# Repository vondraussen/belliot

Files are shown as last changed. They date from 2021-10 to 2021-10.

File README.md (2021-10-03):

# Belliot
Door Bell IoT Hardware.
Made with Kicad.

Used to make my door intercom system a bit more smarter. I have a Siedle HT511-01 which I wanted to control from Home Assistant.

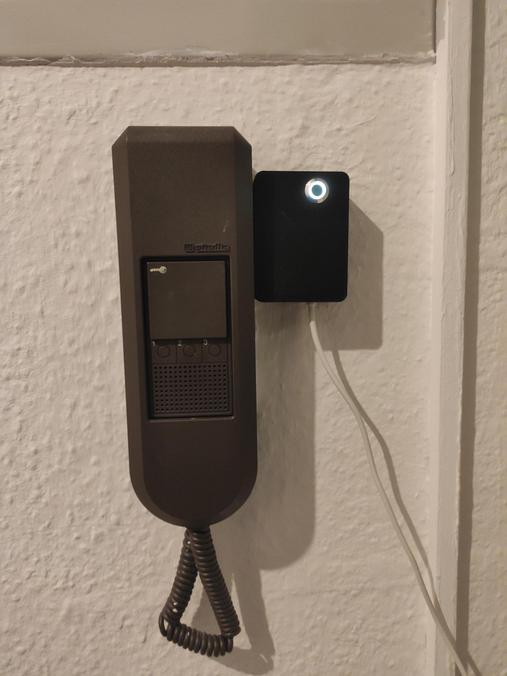
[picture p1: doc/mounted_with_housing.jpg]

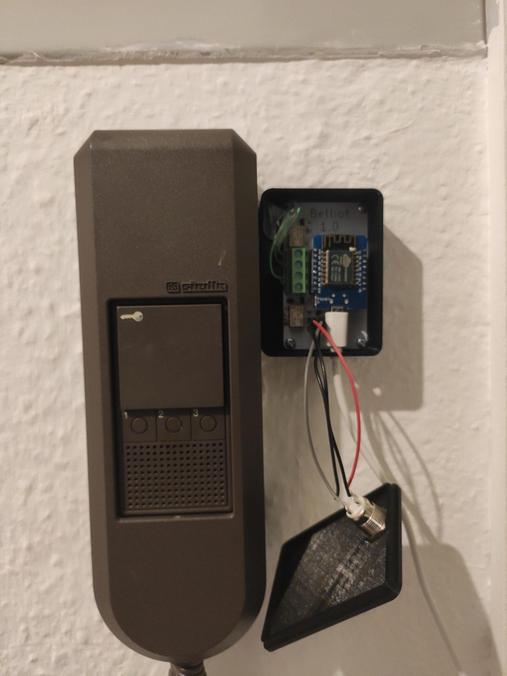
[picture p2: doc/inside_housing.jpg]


## Features
+ Mute bell via relay
+ Actuate door opener via relay
+ One button to mute/unmute bell at the hardware
+ One LED to indicate mute state

## Hardware
+ ESP8266 WeMos D1 Mini
+ AC Optocoupler VOS628A-3T
+ 2x Relais G6K-2F-Y

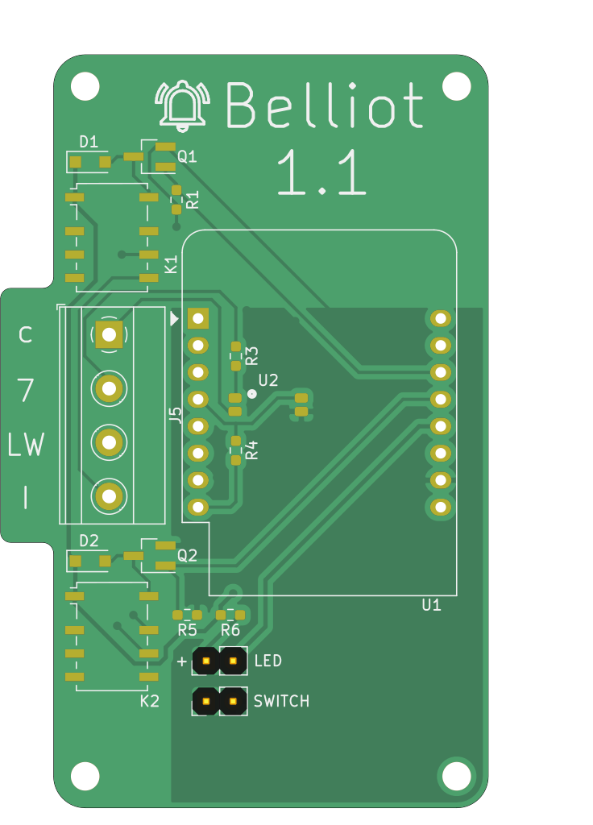
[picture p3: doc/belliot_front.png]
front

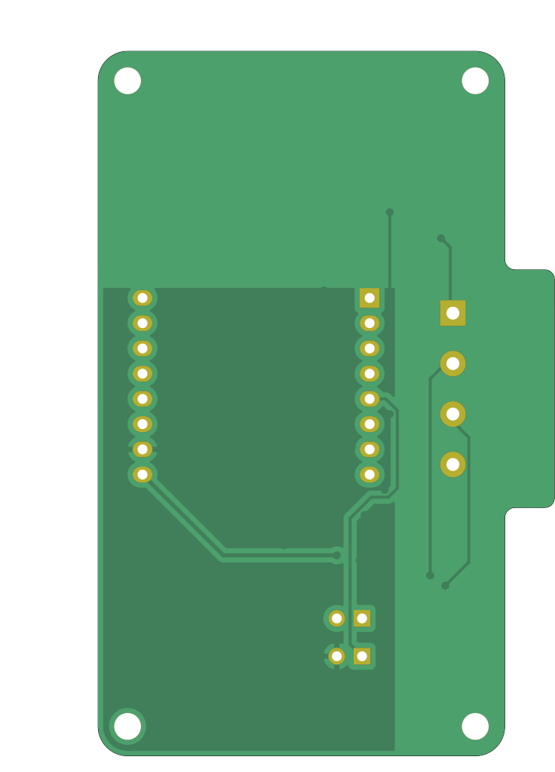
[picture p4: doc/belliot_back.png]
back


## Housing
Todo

## Software
The software repository is [belliot_sw](https://github.com/vondraussen/belliot_sw).

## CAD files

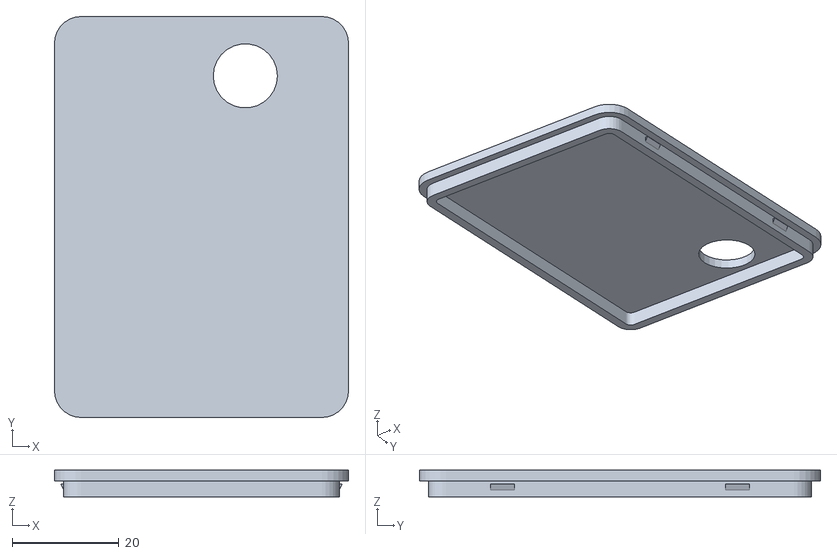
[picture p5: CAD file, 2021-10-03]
housing/belliot-upper_housing.stl
55.0 x 75.0 x 5.00

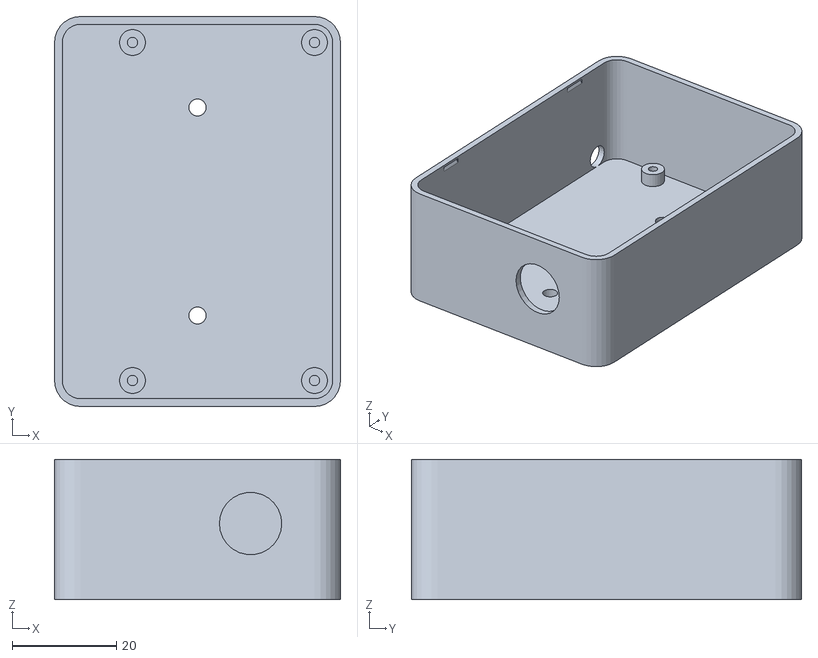
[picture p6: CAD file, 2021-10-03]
housing/belliot-lower_housing.stl
55.0 x 75.0 x 27.0

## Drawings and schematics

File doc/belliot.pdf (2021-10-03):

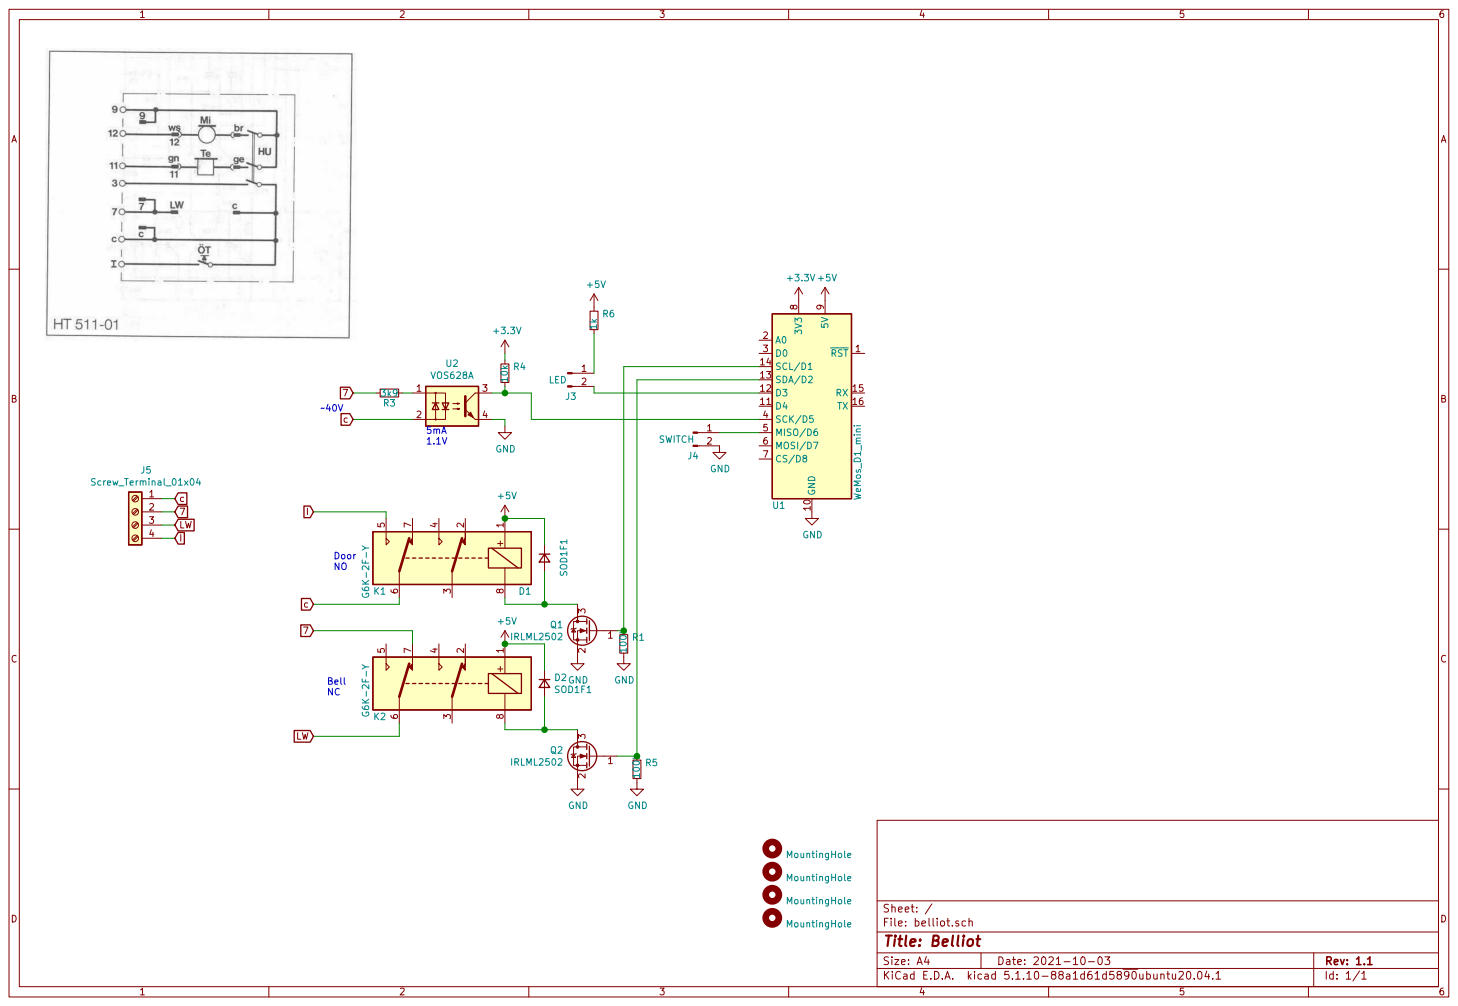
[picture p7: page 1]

Id: 1/1 Title: Belliot File: belliot.sch Sheet: / 1

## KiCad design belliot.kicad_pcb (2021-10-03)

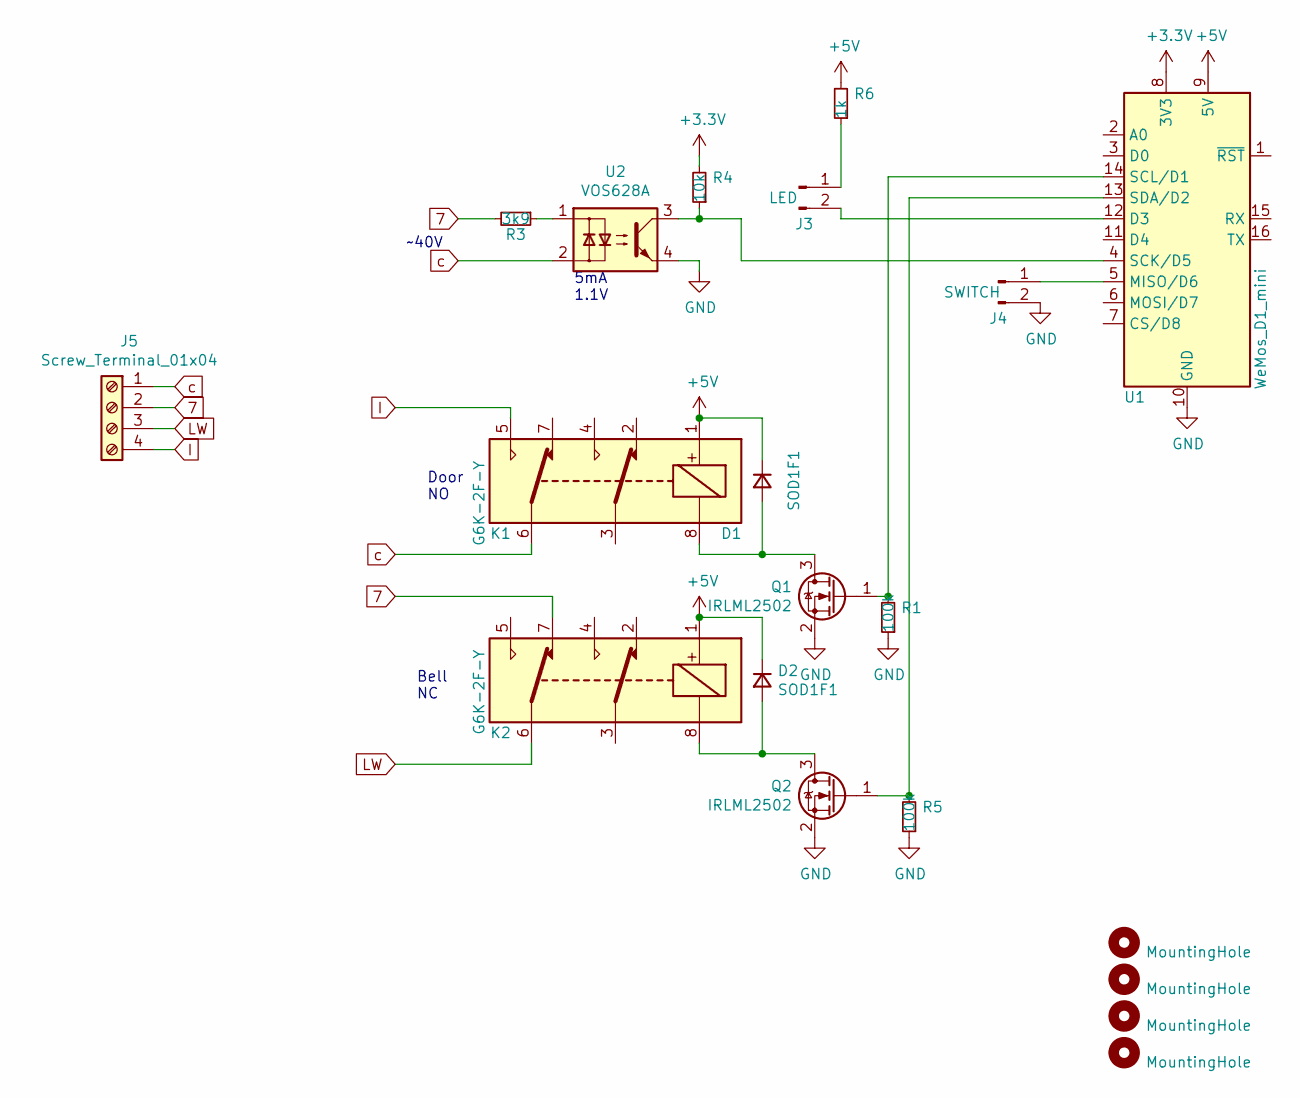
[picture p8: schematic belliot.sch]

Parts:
D1, D2: SOD1F1; D_SOD-123F; LCSC C2128
H1, H2, H3, H4: MountingHole; MountingHole_2.7mm
J3: LED; PinHeader_1x02_P2.54mm_Vertical
J4: SWITCH; PinHeader_1x02_P2.54mm_Vertical
J5: Screw_Terminal_01x04; TerminalBlock_Phoenix_MKDS-1,5-4-5.08_1x04_P5.08mm_Horizont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; LCSC C173286
K1, K2: G6K-2F-Y; Relay_DPDT_Omron_G6K-2F-Y; LCSC C231389
Q1, Q2: IRLML2502; SOT-23_Handsoldering; LCSC C8545
R1, R5: 100k; R_0603_1608Metric_Pad0.98x0.95mm_HandSolder; LCSC C25803
R3: 3k9; R_0603_1608Metric_Pad0.98x0.95mm_HandSolder; LCSC C23018
R4: 10k; R_0603_1608Metric_Pad0.98x0.95mm_HandSolder; LCSC C25804
R6: 1k; R_0603_1608Metric_Pad0.98x0.95mm_HandSolder; LCSC C21190
U1: WeMos_D1_mini; WEMOS_D1_mini_light
U2: VOS628A; SSOP-4_4.4x2.6mm_P1.27mm

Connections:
7: J5.2, K2.7, R3.2
+3V3: R4.2, U1.8 (3V3)
+5V: D1.1 (K), D2.1 (K), K1.1, K2.1, R6.2, U1.9 (5V)
GND: J4.2, Q1.2 (S), Q2.2 (S), R1.1, R5.1, U1.10 (GND), U2.4
I: J5.4, K1.5
LW: J5.3, K2.6
unnamed: D1.2 (A), K1.8, Q1.3 (D)
unnamed: D2.2 (A), K2.8, Q2.3 (D)
unnamed: J3.1, R6.1
unnamed: J3.2, U1.12 (D3)
unnamed: J4.1, U1.5 (MISO/D6)
unnamed: Q1.1 (G), R1.2, U1.14 (SCL/D1)
unnamed: Q2.1 (G), R5.2, U1.13 (SDA/D2)
unnamed: R3.1, U2.1
unnamed: R4.1, U1.4 (SCK/D5), U2.3
c: J5.1, K1.6, U2.2

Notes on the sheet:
5mA 1.1V
~~40V
Bell NC
Door NO

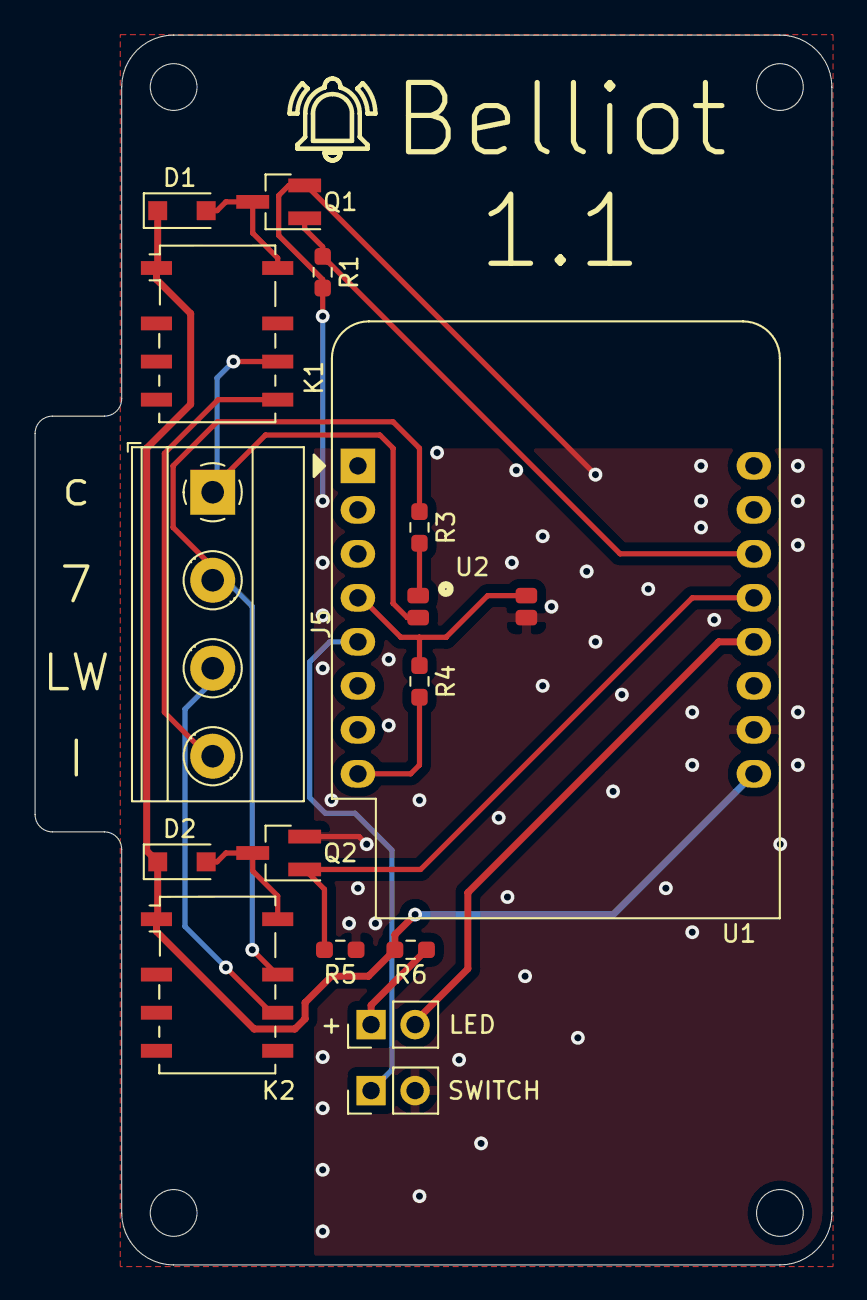
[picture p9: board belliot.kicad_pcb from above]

Board: 2 copper layers, 46.0 x 71.0 mm, 20 parts (0 on the bottom side), 16 nets.

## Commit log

2021-09-19 init commit
    [belliot.kicad_pcb, belliot.sch]
2021-09-20 add d1 3d package
    [belliot.kicad_pcb]
2021-10-03 some improvements
    [belliot.kicad_pcb, belliot.sch]
2021-10-03 add pcb pics
2021-10-03 add name and rev to schematic
    [belliot.sch]
2021-10-03 add schematic pdf
2021-10-03 add inital housing stl files
    [belliot-lower_housing.stl, belliot-upper_housing.stl]
